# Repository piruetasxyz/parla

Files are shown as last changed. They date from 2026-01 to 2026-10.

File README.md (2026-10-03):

# parla

Un proyecto de piruetas, 2026.

## Módulos

Cada módulo tiene su propia carpeta con un proyecto de KiCad, organizado por versión y revisión (por ejemplo `parla-linea/parla-linea-v-0-rev-a/`).

| | parla-linea | parla-eurorack | parla-guitarra | parla-estereo |
| --- | --- | --- | --- | --- |
| formato | standalone | eurorack | standalone | standalone |
| entrada alimentación | batería 9V | por definir | batería 9V | por definir |
| chip | PAM8403 | por definir | LM386 | PAM8403 |
| interfaz | 1x pote | 2x potes | 1x pote | 2x potes |
| entrada señal | 1x línea TRS | 1x eurorack | 1x guitarra | 1x línea TRS |
| conector entrada | TRS 1/8" | TS 1/8" | TS 1/4" | TRS 1/8" |
| salidas | 1x parlante, 1x línea | 1x parlante, 1x eurorack | 1x parlante | 2x parlantes |
| conector salida | parlante: por definir, línea: TRS 1/8" | parlante: por definir, eurorack: TS 1/8" | parlante: por definir | parlantes: por definir |

### Extensores

| | parla-linea-extensor  | parla-eurorack-extensor |
| --- | --- | --- |
| formato | standalone | eurorack |
| alimentación | ninguna | por definir |
| chip | ninguno | por definir |
| interfaz | — | — |
| entradas | 1x línea | 1x eurorack |
| conector entrada | TRS 1/8" | TS 1/8" |
| salidas | 1x parlante | 1x parlante |
| conector salida  | parlante: por definir | parlante: por definir |

## Documentación

Esquemáticos, placas y bill of materials (BOM) de cada módulo, generados automáticamente: [docs](./docs/README.md).

### Agregar las bibliotecas de parla-linea a KiCad

Las bibliotecas generadas están en `parla-linea/parla-linea-v-0-rev-a/bibliotecas/`.
Para que KiCad las encuentre, abre primero el proyecto
`parla-linea/parla-linea-v-0-rev-a/parla-linea-v-0-rev-a.kicad_pro` y agrégalas
como bibliotecas específicas de ese proyecto:

1. En KiCad, abre **Preferencias → Administrar bibliotecas de símbolos…**.
2. En **Bibliotecas específicas del proyecto**, pulsa **Añadir biblioteca existente**
   y selecciona
   `parla-linea/parla-linea-v-0-rev-a/bibliotecas/parla-linea-v-0-rev-a.kicad_sym`.
3. Abre **Preferencias → Administrar bibliotecas de huellas…**.
4. En **Bibliotecas específicas del proyecto**, pulsa **Añadir biblioteca existente**
   y selecciona la carpeta
   `parla-linea/parla-linea-v-0-rev-a/bibliotecas/parla-linea-v-0-rev-a.pretty`
   (no un archivo dentro de ella).
5. Confirma los cambios. Las bibliotecas deberían aparecer en los selectores de
   símbolos y huellas del proyecto.

Agrégalas como bibliotecas **específicas del proyecto**, no globales, para que las
rutas queden asociadas a este proyecto. Los modelos 3D están en la carpeta hermana
`parla-linea/parla-linea-v-0-rev-a/bibliotecas/parla-linea-v-0-rev-a.3dshapes/`;
las huellas los referencian desde ahí, así que no hace falta registrarlos como
biblioteca aparte. Si el proyecto ya estaba abierto mientras agregabas las
bibliotecas, cierra y vuelve a abrir el proyecto.

### Enlaces por módulo

- parla-linea: [carpeta](https://github.com/piruetasxyz/parla/tree/main/parla-linea), [docs](./docs/parla-linea.md)
- parla-eurorack: [carpeta](https://github.com/piruetasxyz/parla/tree/main/parla-eurorack), [docs](./docs/parla-eurorack.md)
- parla-guitarra: [carpeta](https://github.com/piruetasxyz/parla/tree/main/parla-guitarra), [docs](./docs/parla-guitarra.md)
- parla-estereo: [carpeta](https://github.com/piruetasxyz/parla/tree/main/parla-estereo), [docs](./docs/parla-estereo.md)
- parla-linea-extensor: [carpeta](https://github.com/piruetasxyz/parla/tree/main/parla-linea-extensor), [docs](./docs/parla-linea-extensor.md)
- parla-eurorack-extensor: [carpeta](https://github.com/piruetasxyz/parla/tree/main/parla-eurorack-extensor), [docs](./docs/parla-eurorack-extensor.md)

## Versiones antiguas

Hicimos versiones preliminares que están en la carpeta [versiones-antiguas](https://github.com/piruetasxyz/parla/tree/main/versiones-antiguas):

- `parla-v0-borrador`: primeros experimentos de esquemáticos (enero-febrero 2026).
- `parla-v0-revA`: versión producida con SMD en JLCPCB.
- `parla-v0-revB`: revisión de la placa con algunos cambios (junio 2026), junto a sus gerbers y archivos de PCBA.
- `graficas`: logos y gráficas usadas en las placas.

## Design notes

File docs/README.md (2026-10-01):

# docs

Documentación por módulo: esquemático, placa y lista de materiales bill of materials (BOM) de la revisión activa de cada uno.

- [parla-linea](./parla-linea.md)
- [parla-linea-extensor](./parla-linea-extensor.md)
- [parla-eurorack](./parla-eurorack.md)
- [parla-eurorack-extensor](./parla-eurorack-extensor.md)
- [parla-guitarra](./parla-guitarra.md)
- [parla-estereo](./parla-estereo.md)

Las capturas SVG y las tablas BOM las genera [generar_docs.py](./generar_docs.py), que corre automáticamente en GitHub Actions (`.github/workflows/actualizar-capturas.yml`) en cada push a `main` que modifica un `.kicad_sch` o `.kicad_pcb`. La revisión activa de cada módulo es la carpeta `<modulo>-v-N-rev-X` más reciente dentro de `parla-*/`, así que al agregar una revisión o un módulo nuevo no hay que editar nada: el script lo detecta y, si el módulo es nuevo, crea su página acá (falta agregarla a mano a esta lista).

Para correrlo localmente (requiere `kicad-cli` de KiCad 10):

```sh
python3 docs/generar_docs.py
```

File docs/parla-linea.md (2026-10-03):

# parla-linea

[volver al índice](./README.md)

## Especificaciones

- formato: standalone
- interfaz: 2x potes
- entradas: 1x TRS 1/8"
- salidas: 1x parlante, 1x TRS 1/8"

## Revisión activa

`v-0-rev-a`

## Esquemático y placa

Generados automáticamente por GitHub Actions a partir de `parla-linea/parla-linea-v-0-rev-a/parla-linea-v-0-rev-a.kicad_sch` y `.kicad_pcb` en cada push que los modifica.

Esquemático de parla-linea v-0-rev-a

Placa de parla-linea v-0-rev-a

## Bill of materials

Generado a partir de `parla-linea/parla-linea-v-0-rev-a/parla-linea-v-0-rev-a.kicad_sch`.

<!-- BOM_TABLE_START -->
| Referencias | Cantidad | Valor | Huella | Descripción |
| --- | --- | --- | --- | --- |
| C1, C6 | 2 | 1u | parla-linea-v-0-rev-a:C0805 | Capacitor cerámico |
| C2, C7 | 2 | 100n | parla-linea-v-0-rev-a:C0805 | Capacitor cerámico |
| C3 | 1 | 100u | parla-linea-v-0-rev-a:CAP-SMD_BD6.3-L6.6-W6.6-LS7.6-FD | Capacitor electrolítico |
| C4 | 1 | 10u | parla-linea-v-0-rev-a:CAP-SMD_BD4.0-L4.3-W4.3-FD | Capacitor electrolítico |
| D1 | 1 | 1N4007 | parla-linea-v-0-rev-a:SOD-323_L1.8-W1.3-LS2.5-RD | Device:D |
| D2 | 1 | LED | Eurocad:LED3mm | Device:LED |
| J1, J2 | 2 | AudioJack2_SwitchT | Connector_Audio:Jack_3.5mm_QingPu_WQP-PJ398SM_Vertical_CircularHoles | Jack de audio mono |
| J3, J5 | 2 | Screw_Terminal_01x02 | TerminalBlock:TerminalBlock_MaiXu_MX126-5.0-02P_1x02_P5.00mm | Bornera de 2 pines |
| J4 | 1 | Conn_01x01 | Connector_Wire:SolderWire-0.25sqmm_1x01_D0.65mm_OD1.7mm | Connector_Generic:Conn_01x01 |
| J6 | 1 | AudioJack3_SwitchTR | Connector_Audio:Jack_3.5mm_CUI_SJ1-3525N_Horizontal | Connector_Audio:AudioJack3_SwitchTR |
| J7 | 1 | Conn_01x03_Pin | Connector_PinHeader_2.54mm:PinHeader_1x03_P2.54mm_Vertical | Connector:Conn_01x03_Pin |
| R1, R2 | 2 | 10k | parla-linea-v-0-rev-a:R0805 | Resistencia |
| R3 | 1 | 1k | parla-linea-v-0-rev-a:R0805 | Resistencia |
| RV1 | 1 | 100kB | Potentiometer_THT:Potentiometer_Alps_RK163_Dual_Horizontal | Device:R_Potentiometer_Dual_Separate |
| U1 | 1 | PAM8403D | parla-linea-v-0-rev-a:SOP-16_L10.0-W3.9-P1.27-LS6.0-BL | Amplificador de audio clase D |
| U2 | 1 | L7805 | parla-linea-v-0-rev-a:TO-252-2_L6.6-W6.1-P4.57-LS9.9-BR-CW | Regulador de voltaje lineal +5V |

21 componentes en total.
<!-- BOM_TABLE_END -->

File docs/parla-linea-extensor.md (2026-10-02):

# parla-linea-extensor

[volver al índice](./README.md)

## Especificaciones

- formato: standalone
- interfaz: —
- entradas: 1x TRS 1/8"
- salidas: 1x parlante

## Revisión activa

`v-0-rev-a`

## Esquemático y placa

Generados automáticamente por GitHub Actions a partir de `parla-linea-extensor/parla-linea-extensor-v-0-rev-a/parla-linea-extensor-v-0-rev-a.kicad_sch` y `.kicad_pcb` en cada push que los modifica.

Esquemático de parla-linea-extensor v-0-rev-a

Placa de parla-linea-extensor v-0-rev-a

## Bill of materials

Generado a partir de `parla-linea-extensor/parla-linea-extensor-v-0-rev-a/parla-linea-extensor-v-0-rev-a.kicad_sch`.

<!-- BOM_TABLE_START -->
| Referencias | Cantidad | Valor | Huella | Descripción |
| --- | --- | --- | --- | --- |
| J1 | 1 | AudioJack3_SwitchT | *(sin huella asignada)* | Jack de audio estéreo |
| LS1 | 1 | Speaker | TerminalBlock:TerminalBlock_MaiXu_MX126-5.0-02P_1x02_P5.00mm | Parlante |

2 componentes en total. Los ítems marcados *(sin huella asignada)* todavía no están completos en el esquemático — hay que completarlos antes de generar gerbers o comprar partes para esta revisión.
<!-- BOM_TABLE_END -->

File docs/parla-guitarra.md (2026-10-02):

# parla-guitarra

[volver al índice](./README.md)

## Especificaciones

- formato: standalone
- interfaz: 1x pote
- entradas: 1x TS 1/4"
- salidas: 1x parlante

## Revisión activa

`v-0-rev-a`

## Esquemático y placa

Generados automáticamente por GitHub Actions a partir de `parla-guitarra/parla-guitarra-v-0-rev-a/parla-guitarra-v-0-rev-a.kicad_sch` y `.kicad_pcb` en cada push que los modifica.

Esquemático de parla-guitarra v-0-rev-a

Placa de parla-guitarra v-0-rev-a

## Bill of materials

Generado a partir de `parla-guitarra/parla-guitarra-v-0-rev-a/parla-guitarra-v-0-rev-a.kicad_sch`.

<!-- BOM_TABLE_START -->
| Referencias | Cantidad | Valor | Huella | Descripción |
| --- | --- | --- | --- | --- |
| C3 | 1 | 220u | *(sin huella asignada)* | Capacitor electrolítico |
| C5 | 1 | 47u | *(sin huella asignada)* | Capacitor electrolítico |
| C6, C7, C9 | 3 | 100n | *(sin huella asignada)* | Capacitor cerámico |
| C8 | 1 | 47n | *(sin huella asignada)* | Capacitor cerámico |
| C10 | 1 | 100p | *(sin huella asignada)* | Capacitor cerámico |
| D1 | 1 | D | *(sin huella asignada)* | Device:D |
| D2, D3 | 2 | 1N4148 | Diode_THT:D_DO-35_SOD27_P7.62mm_Horizontal | Diode:1N4148 |
| J1 | 1 | entrada | *(sin huella asignada)* | Jack de audio mono |
| J2 | 1 | Screw_Terminal_01x02 | TerminalBlock:TerminalBlock_MaiXu_MX126-5.0-02P_1x02_P5.00mm | Bornera de 2 pines |
| LS1 | 1 | Speaker | TerminalBlock:TerminalBlock_MaiXu_MX126-5.0-02P_1x02_P5.00mm | Parlante |
| R1 | 1 | 10 | *(sin huella asignada)* | Resistencia |
| R2 | 1 | 1M | *(sin huella asignada)* | Resistencia |
| RV1 | 1 | 1k | *(sin huella asignada)* | Potenciómetro |
| U1 | 1 | LM386 | Package_DIP:DIP-8_W7.62mm_Socket_LongPads | Amplificador de audio LM386 |
| U2 | 1 | TL072 | *(sin huella asignada)* | Amplifier_Operational:TL072 |

18 componentes en total. Los ítems marcados *(sin huella asignada)* todavía no están completos en el esquemático — hay que completarlos antes de generar gerbers o comprar partes para esta revisión.
<!-- BOM_TABLE_END -->

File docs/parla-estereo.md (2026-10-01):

# parla-estereo

[volver al índice](./README.md)

## Especificaciones

- formato: standalone
- interfaz: 2x potes
- entradas: 1x TRS 1/8"
- salidas: 2x parlantes

## Revisión activa

`v-0-rev-a`

## Esquemático y placa

Generados automáticamente por GitHub Actions a partir de `parla-estereo/parla-estereo-v-0-rev-a/parla-estereo-v-0-rev-a.kicad_sch` y `.kicad_pcb` en cada push que los modifica.

Esquemático de parla-estereo v-0-rev-a

Placa de parla-estereo v-0-rev-a

## Bill of materials

Generado a partir de `parla-estereo/parla-estereo-v-0-rev-a/parla-estereo-v-0-rev-a.kicad_sch`.

<!-- BOM_TABLE_START -->
*(el esquemático todavía no tiene componentes)*
<!-- BOM_TABLE_END -->

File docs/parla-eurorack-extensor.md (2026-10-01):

# parla-eurorack-extensor

[volver al índice](./README.md)

## Especificaciones

- formato: eurorack
- interfaz: —
- entradas: 1x TS 1/8"
- salidas: 1x parlante

## Revisión activa

`v-0-rev-a`

## Esquemático y placa

Generados automáticamente por GitHub Actions a partir de `parla-eurorack-extensor/parla-eurorack-extensor-v-0-rev-a/parla-eurorack-extensor-v-0-rev-a.kicad_sch` y `.kicad_pcb` en cada push que los modifica.

Esquemático de parla-eurorack-extensor v-0-rev-a

Placa de parla-eurorack-extensor v-0-rev-a

## Bill of materials

Generado a partir de `parla-eurorack-extensor/parla-eurorack-extensor-v-0-rev-a/parla-eurorack-extensor-v-0-rev-a.kicad_sch`.

<!-- BOM_TABLE_START -->
*(el esquemático todavía no tiene componentes)*
<!-- BOM_TABLE_END -->

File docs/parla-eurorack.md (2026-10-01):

# parla-eurorack

[volver al índice](./README.md)

## Especificaciones

- formato: eurorack
- interfaz: 2x potes
- entradas: 1x TS 1/8"
- salidas: 1x parlante, 1x TS 1/8"

## Revisión activa

`v-0-rev-a`

## Esquemático y placa

Generados automáticamente por GitHub Actions a partir de `parla-eurorack/parla-eurorack-v-0-rev-a/parla-eurorack-v-0-rev-a.kicad_sch` y `.kicad_pcb` en cada push que los modifica.

Esquemático de parla-eurorack v-0-rev-a

Placa de parla-eurorack v-0-rev-a

## Bill of materials

Generado a partir de `parla-eurorack/parla-eurorack-v-0-rev-a/parla-eurorack-v-0-rev-a.kicad_sch`.

<!-- BOM_TABLE_START -->
*(el esquemático todavía no tiene componentes)*
<!-- BOM_TABLE_END -->

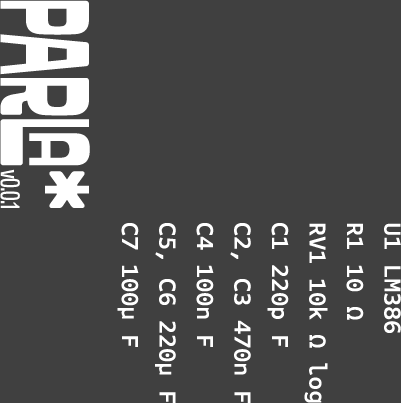
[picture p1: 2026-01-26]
versiones-antiguas/graficas/parla_info_square@300x.png

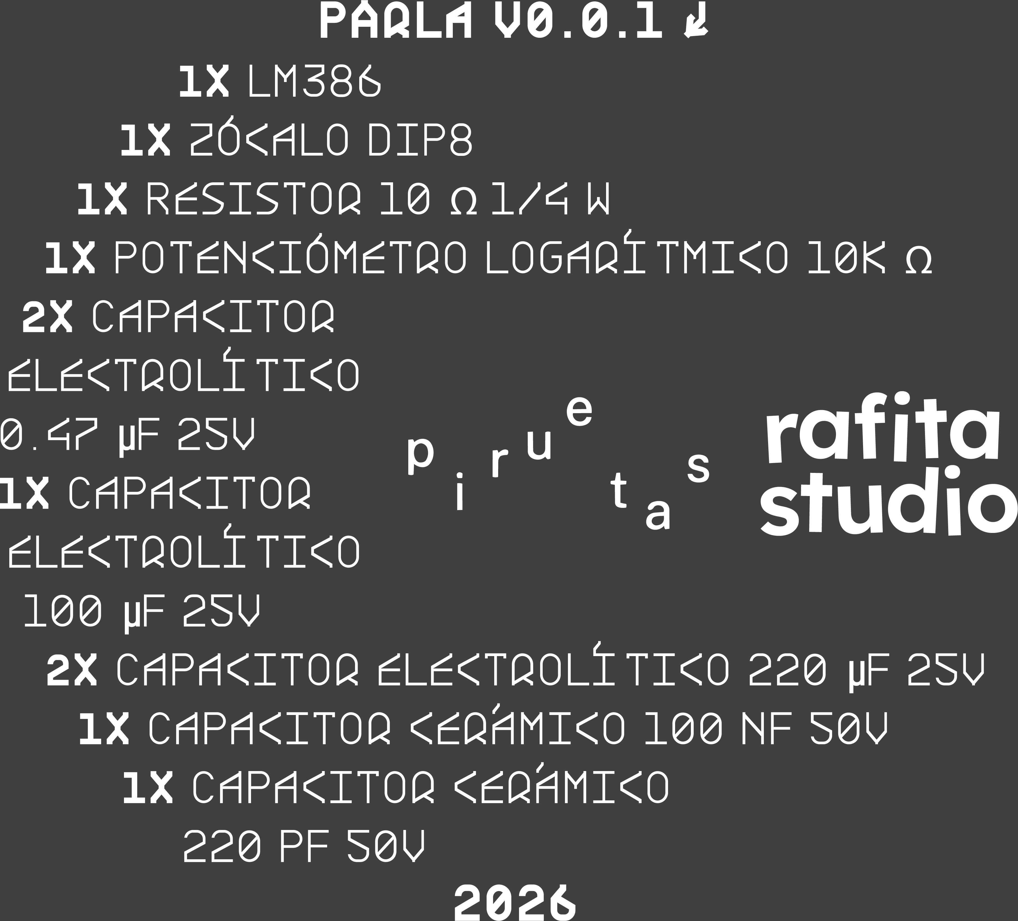
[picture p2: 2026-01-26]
versiones-antiguas/graficas/parla_info@300x.png

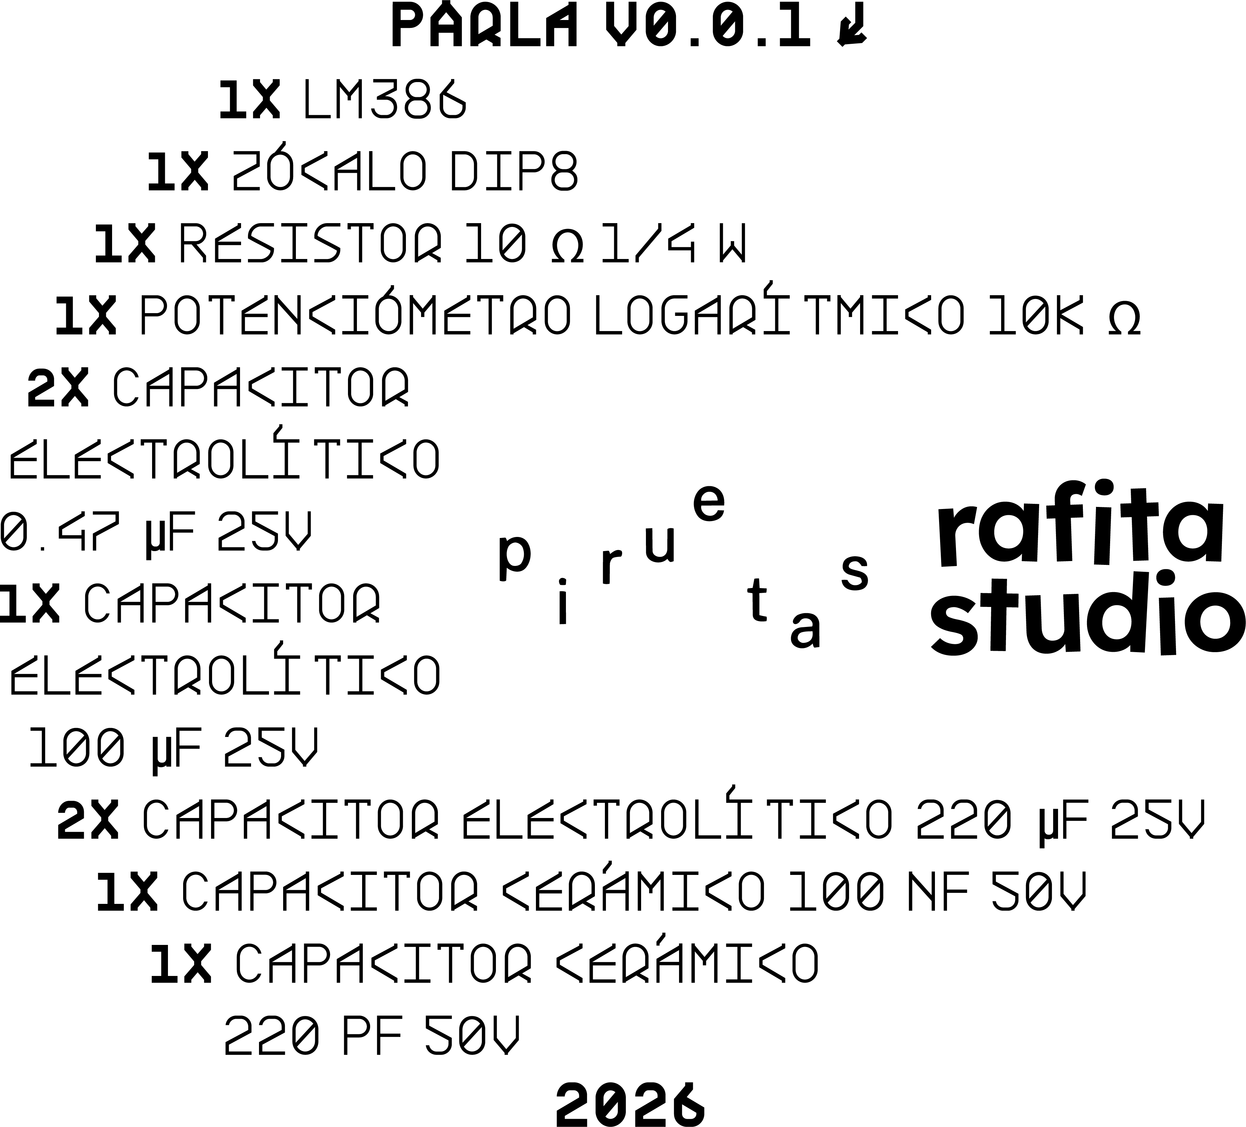
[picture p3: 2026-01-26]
versiones-antiguas/graficas/parla_infoBlack@300x.png

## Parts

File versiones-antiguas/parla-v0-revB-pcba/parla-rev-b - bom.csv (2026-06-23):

Comment | Designator | Footprint | LCSC Part Number
470n | C1,C2 | Capacitor_SMD:C_Elec_4x5.4 | C2895732
100n | C3,C10 | Capacitor_SMD:C_0805_2012Metric_Pad1.18x1.45mm_HandSolder | C49678
1u | C4,C5,C6 | Capacitor_SMD:C_0805_2012Metric_Pad1.18x1.45mm_HandSolder | C77083
100u | C7 | Capacitor_SMD:CP_Elec_6.3x7.7 | C3347
220u | C8 | Capacitor_SMD:CP_Elec_6.3x5.4 | C3342
10u | C9 | Capacitor_SMD:CP_Elec_4x5.4 | C3357
1N4007 | D1 | Diode_SMD:D_SOD-323_HandSoldering | C193404
10k | R3,R4 | Resistor_SMD:R_0805_2012Metric_Pad1.20x1.40mm_HandSolder | C17414
1k | R5 | Resistor_SMD:R_0805_2012Metric_Pad1.20x1.40mm_HandSolder | C2907232
PAM8403D | U1 | Package_SO:SOP-16_4.4x10.4mm_P1.27mm | C5122557
L7805 | U2 | Package_TO_SOT_SMD:TO-252-2 | C19626525

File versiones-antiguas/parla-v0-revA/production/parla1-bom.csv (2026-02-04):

Comment | Designator | Footprint | LCSC Part Number
220p | C1 | C_0805_2012Metric | C107145
470n | C2,C3 | CP_Elec_4x5.4 | C22387960
100n | C4 | C_0805_2012Metric | C49678
220u | C5,C6 | CP_Elec_6.3x5.4 | C3345
100u | C7 | CP_Elec_5x5.4 | C72473
1n4007 | D1 | D_SOD-323 | C193404
10R | R1 | R_0805_2012Metric | C2907296

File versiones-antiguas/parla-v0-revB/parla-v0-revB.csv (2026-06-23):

Reference | Value | Footprint | LCSC
C1,C2 | 470n | Capacitor_SMD:C_Elec_4x5.4 | C2895732
C3,C10 | 100n | Capacitor_SMD:C_0805_2012Metric_Pad1.18x1.45mm_HandSolder | C49678
C4,C5,C6 | 1u | Capacitor_SMD:C_0805_2012Metric_Pad1.18x1.45mm_HandSolder | C77083
C7 | 100u | Capacitor_SMD:CP_Elec_5x5.4 | C3347
C8 | 220u | Capacitor_SMD:CP_Elec_6.3x7.7 | C3342
C9 | 10u | Capacitor_SMD:CP_Elec_4x5.4 | C3357
D1 | 1N4007 | Diode_SMD:D_SOD-323_HandSoldering | C193404
D8 | LED | LED_THT:LED_D5.0mm
J1,J2,J3,J4 | AudioJack2_SwitchT | dis8644:PJ301M-12-T_TN_S
J5 | Barrel_Jack_Switch | Connector_BarrelJack:BarrelJack_Horizontal
R3,R4 | 10k | Resistor_SMD:R_0805_2012Metric_Pad1.20x1.40mm_HandSolder | C17414
R5 | 1k | Resistor_SMD:R_0805_2012Metric_Pad1.20x1.40mm_HandSolder | C2907232
RV1,RV2 | 50k | Potentiometer_THT:Potentiometer_Bourns_PTV09A-1_Single_Vertical
SW3 | SW_SPDT | dis8644:spdt_ssd12d00g3
U1 | PAM8403D | Package_SO:SOP-16_4.4x10.4mm_P1.27mm | C5122557
U2 | L7805 | Package_TO_SOT_SMD:TO-252-2 | C19626525

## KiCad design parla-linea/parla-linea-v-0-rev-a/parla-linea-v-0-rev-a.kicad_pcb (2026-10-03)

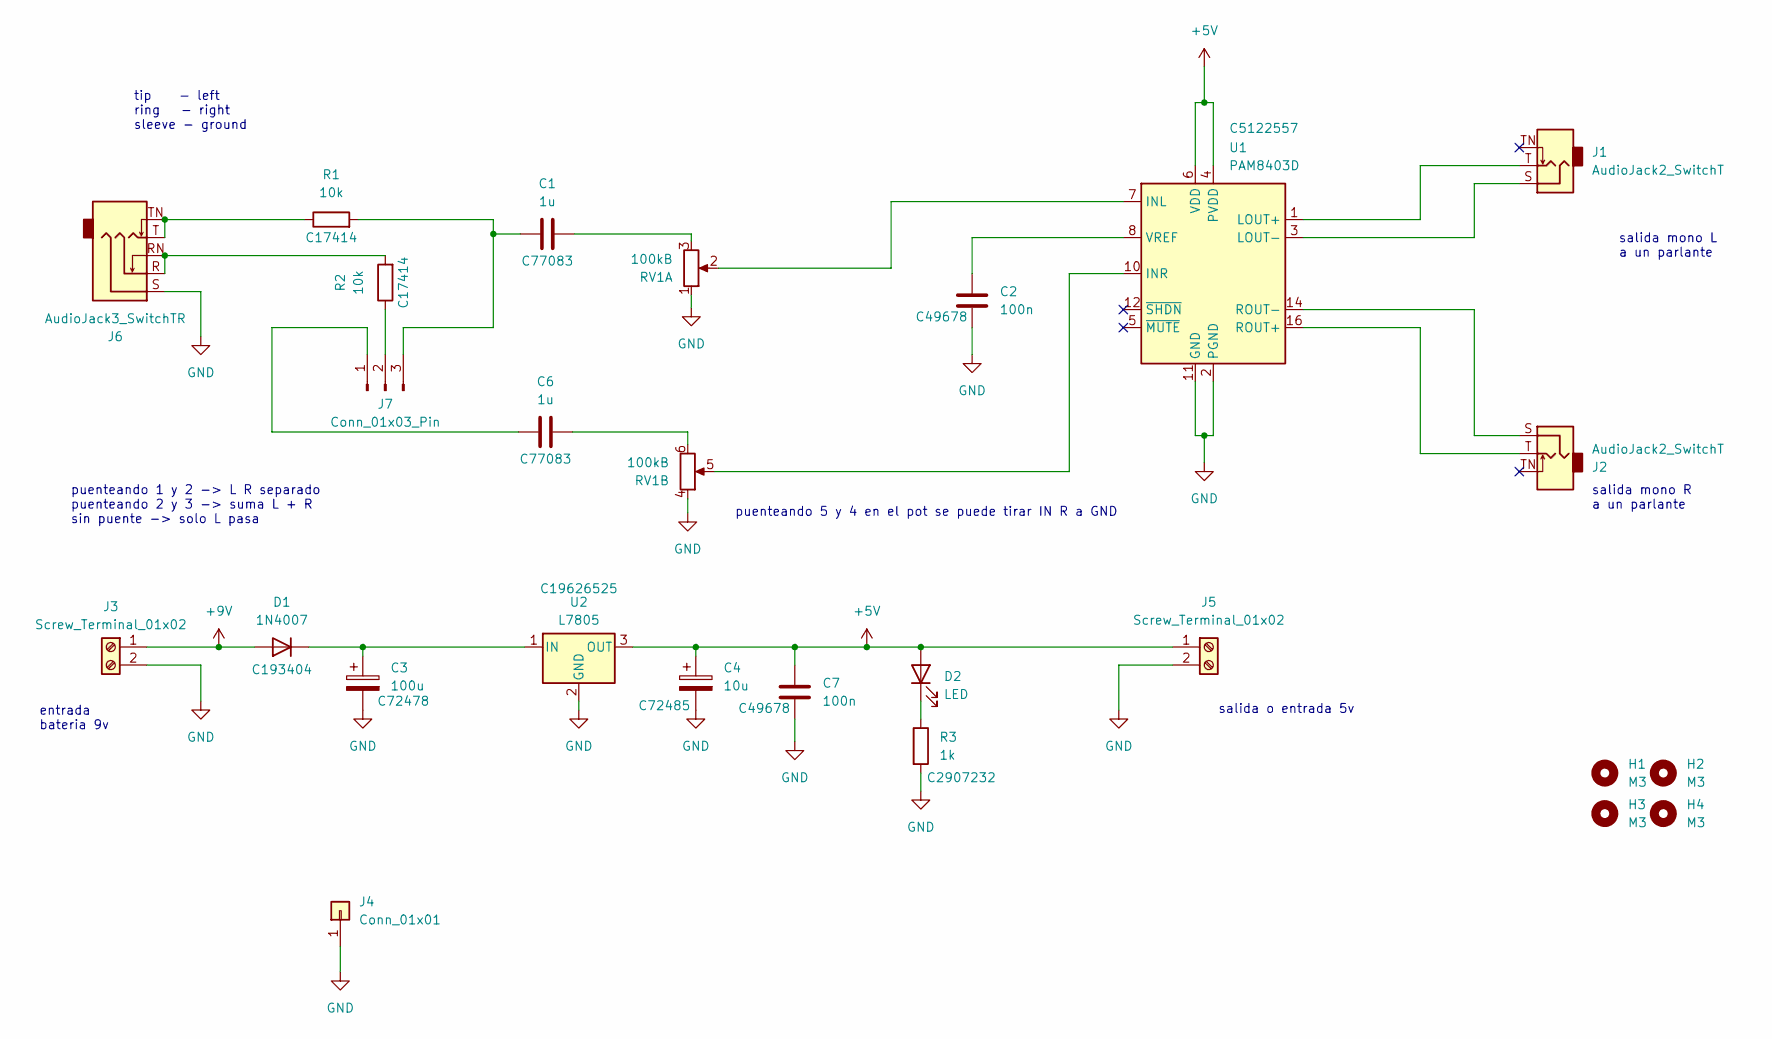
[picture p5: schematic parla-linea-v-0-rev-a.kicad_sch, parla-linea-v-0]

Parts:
C1, C6: 1u; C0805; LCSC C77083
C2, C7: 100n; C0805; LCSC C49678
C3: 100u; CAP-SMD_BD6.3-L6.6-W6.6-LS7.6-FD; LCSC C72478
C4: 10u; CAP-SMD_BD4.0-L4.3-W4.3-FD; LCSC C72485
D1: 1N4007; SOD-323_L1.8-W1.3-LS2.5-RD; LCSC C193404
D2: LED; LED3mm
H1, H2, H3, H4: M3; MountingHole_3.2mm_M3
J1, J2: AudioJack2_SwitchT; Jack_3.5mm_QingPu_WQP-PJ398SM_Vertical_CircularHoles
J3, J5: Screw_Terminal_01x02; TerminalBlock_MaiXu_MX126-5.0-02P_1x02_P5.00mm
J4: Conn_01x01; SolderWire-0.25sqmm_1x01_D0.65mm_OD1.7mm
J6: AudioJack3_SwitchTR; Jack_3.5mm_CUI_SJ1-3525N_Horizontal
J7: Conn_01x03_Pin; PinHeader_1x03_P2.54mm_Vertical
R1, R2: 10k; R0805; LCSC C17414
R3: 1k; R0805; LCSC C2907232
RV1: 100kB; Potentiometer_Alps_RK163_Dual_Horizontal
U1: PAM8403D; SOP-16_L10.0-W3.9-P1.27-LS6.0-BL; LCSC C5122557
U2: L7805; TO-252-2_L6.6-W6.1-P4.57-LS9.9-BR-CW; LCSC C19626525

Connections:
+5V: C4.1, C7.1, D2.2 (A), J5.1, U1.4 (PVDD), U1.6 (VDD), U1.13 (PVDD), U2.3 (OUT)
+9V: D1.2 (A), J3.1
GND: C2.2, C3.2, C4.2, C7.2, J3.2, J4.1 (Pin_1_1), J5.2, J6.S, R3.2, RV1.1, RV1.4, U1.2 (PGND), U1.11 (GND), U1.15 (PGND), U2.2 (GND)
unnamed: C1.2, RV1.3
unnamed: C6.2, RV1.6
unnamed: C3.1, D1.1 (K), U2.1 (IN)
unnamed: D2.1 (K), R3.1
unnamed: J6.R, J6.RN, R2.2
unnamed: J6.T, J6.TN, R1.1
unnamed: C6.1, J7.1
unnamed: J7.2, R2.1
unnamed: C1.1, J7.3, R1.2
unnamed: RV1.2, U1.7 (INL)
unnamed: RV1.5, U1.10 (INR)
unnamed: J1.T, U1.1 (LOUT+)
unnamed: J1.S, U1.3 (LOUT-)
unnamed: J2.T, U1.16 (ROUT+)
unnamed: J2.S, U1.14 (ROUT-)
unnamed: C2.1, U1.8 (VREF)

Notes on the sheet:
salida mono L a un parlante
tip - left ring - right sleeve - ground
salida mono R a un parlante
puenteando 1 y 2 -> L R separado puenteando 2 y 3 -> suma L + R sin puente -> solo L pasa
entrada bateria 9v
puenteando 5 y 4 en el pot se puede tirar IN R a GND
salida o entrada 5v

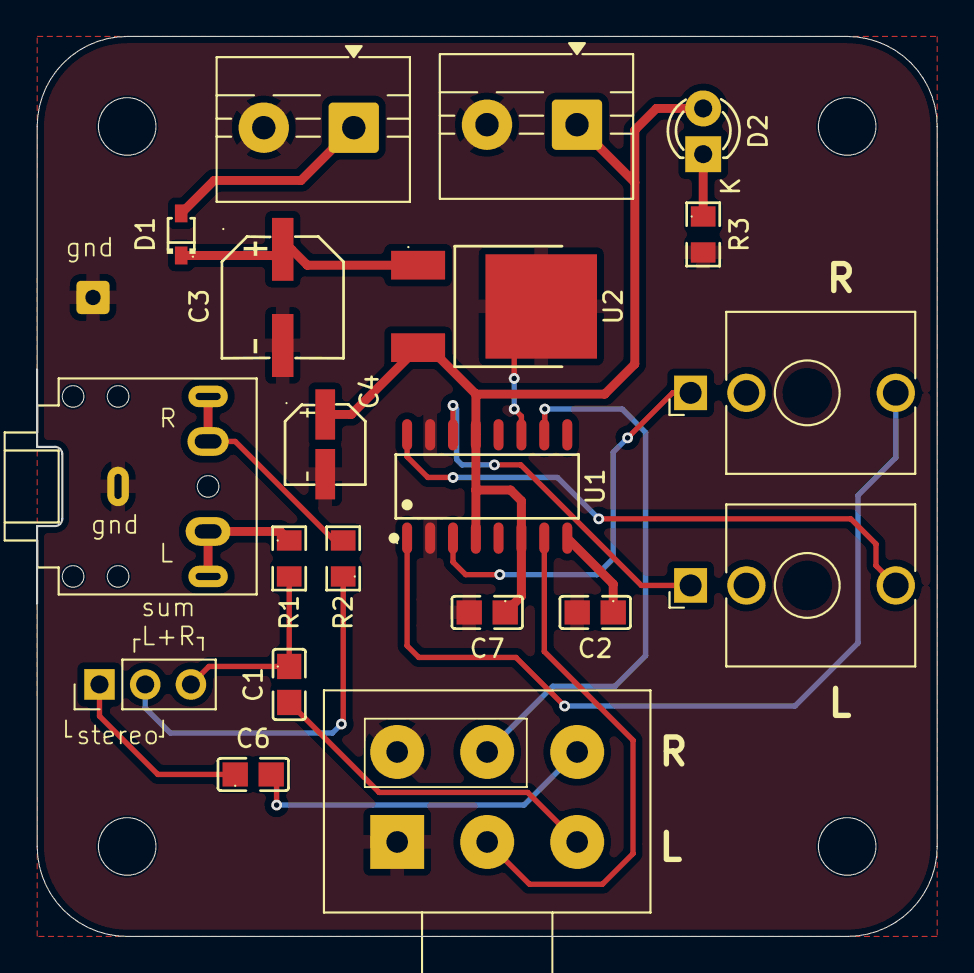
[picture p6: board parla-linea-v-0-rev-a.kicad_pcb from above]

Board: 2 copper layers, 50.0 x 50.0 mm, 25 parts (0 on the bottom side), 19 nets.

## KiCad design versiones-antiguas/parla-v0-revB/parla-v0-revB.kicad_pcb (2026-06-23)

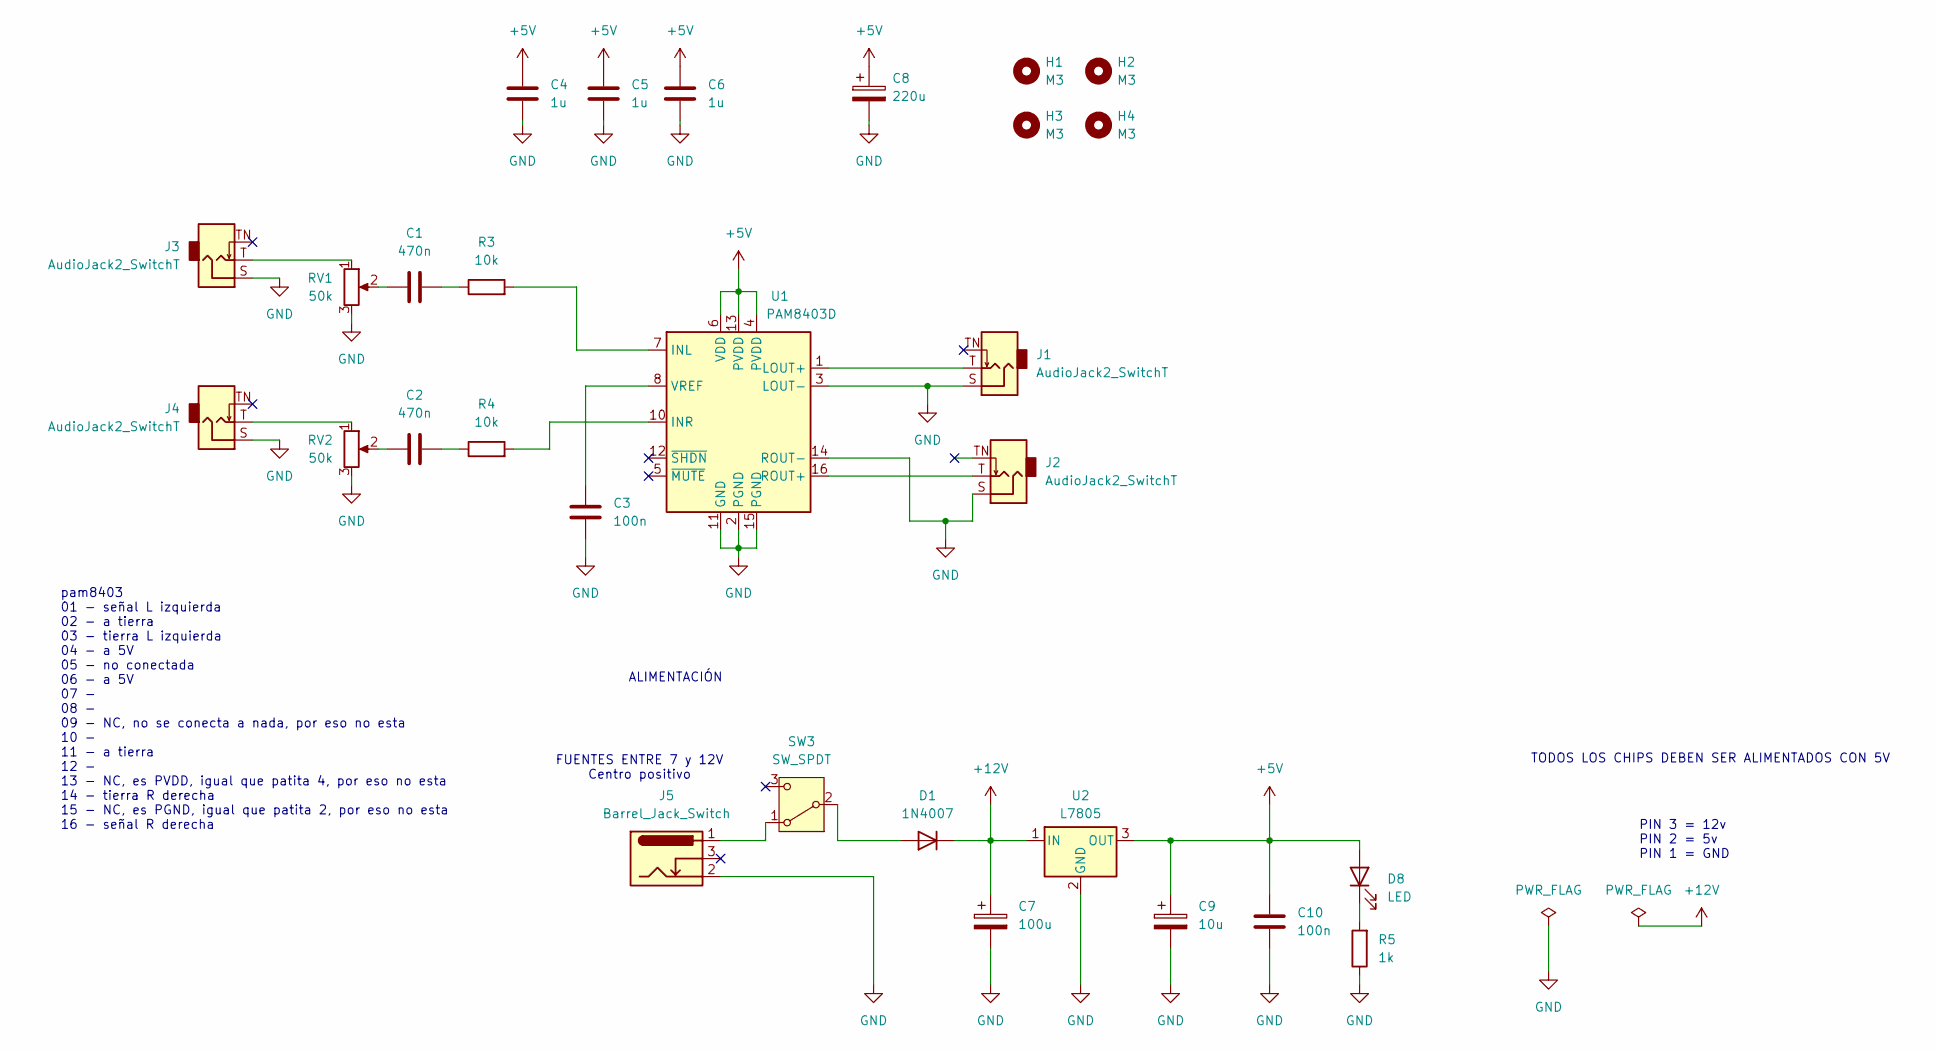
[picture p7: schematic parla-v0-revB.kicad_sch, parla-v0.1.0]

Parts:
C1, C2: 470n; C_Elec_4x5.4; LCSC C2895732
C3, C10: 100n; C_0805_2012Metric_Pad1.18x1.45mm_HandSolder; LCSC C49678
C4, C5, C6: 1u; C_0805_2012Metric_Pad1.18x1.45mm_HandSolder; LCSC C77083
C7: 100u; CP_Elec_5x5.4; LCSC C3347
C8: 220u; CP_Elec_6.3x7.7; LCSC C3342
C9: 10u; CP_Elec_4x5.4; LCSC C3357
D1: 1N4007; D_SOD-323_HandSoldering; LCSC C193404
D8: LED; LED_D5.0mm
H1, H2, H3, H4: M3; MountingHole_3.2mm_M3
J1, J2, J3, J4: AudioJack2_SwitchT; PJ301M-12-T_TN_S
J5: Barrel_Jack_Switch; BarrelJack_Horizontal
R3, R4: 10k; R_0805_2012Metric_Pad1.20x1.40mm_HandSolder; LCSC C17414
R5: 1k; R_0805_2012Metric_Pad1.20x1.40mm_HandSolder; LCSC C2907232
RV1, RV2: 50k; Potentiometer_Bourns_PTV09A-1_Single_Vertical
SW3: SW_SPDT; spdt_ssd12d00g3
U1: PAM8403D; SOP-16_4.4x10.4mm_P1.27mm; LCSC C5122557
U2: L7805; TO-252-2; LCSC C19626525

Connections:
+5V: C4.2, C5.2, C6.2, C8.1, C9.1, C10.1, D8.2 (A), U1.4 (PVDD), U1.6 (VDD), U1.13 (PVDD), U2.3 (OUT)
+12V: C7.1, D1.1 (K), U2.1 (IN)
GND: C3.2, C4.1, C5.1, C6.1, C7.2, C8.2, C9.2, C10.2, J1.S, J2.S, J3.S, J4.S, J5.2, R5.1, RV1.3, RV2.3, U1.2 (PGND), U1.3 (LOUT-), U1.11 (GND), U1.14 (ROUT-), U1.15 (PGND), U2.2 (GND)
unnamed: C1.1, RV1.2
unnamed: C1.2, R3.1
unnamed: C2.1, RV2.2
unnamed: C2.2, R4.1
unnamed: D1.2 (A), SW3.2 (B)
unnamed: D8.1 (K), R5.2
unnamed: J3.T, RV1.1
unnamed: J4.T, RV2.1
unnamed: J5.1, SW3.1 (A)
unnamed: R3.2, U1.7 (INL)
unnamed: R4.2, U1.10 (INR)
unnamed: J1.T, U1.1 (LOUT+)
unnamed: J2.T, U1.16 (ROUT+)
unnamed: C3.1, U1.8 (VREF)

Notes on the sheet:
FUENTES ENTRE 7 y 12V Centro positivo
PIN 3 = 12v PIN 2 = 5v PIN 1 = GND
TODOS LOS CHIPS DEBEN SER ALIMENTADOS CON 5V
ALIMENTACIÓN
pam8403 01 - señal L izquierda 02 - a tierra 03 - tierra L izquierda 04 - a 5V 05 - no conectada 06 - a 5V 07 - 08 - 09 - NC, no se conecta a nada, por eso no esta 10 - 11 - a tierra 12 - 13 - NC, es PVDD, igual que patita 4, por eso no esta 14 - tierra R derecha 15 - NC, es PGND, igual que patita 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

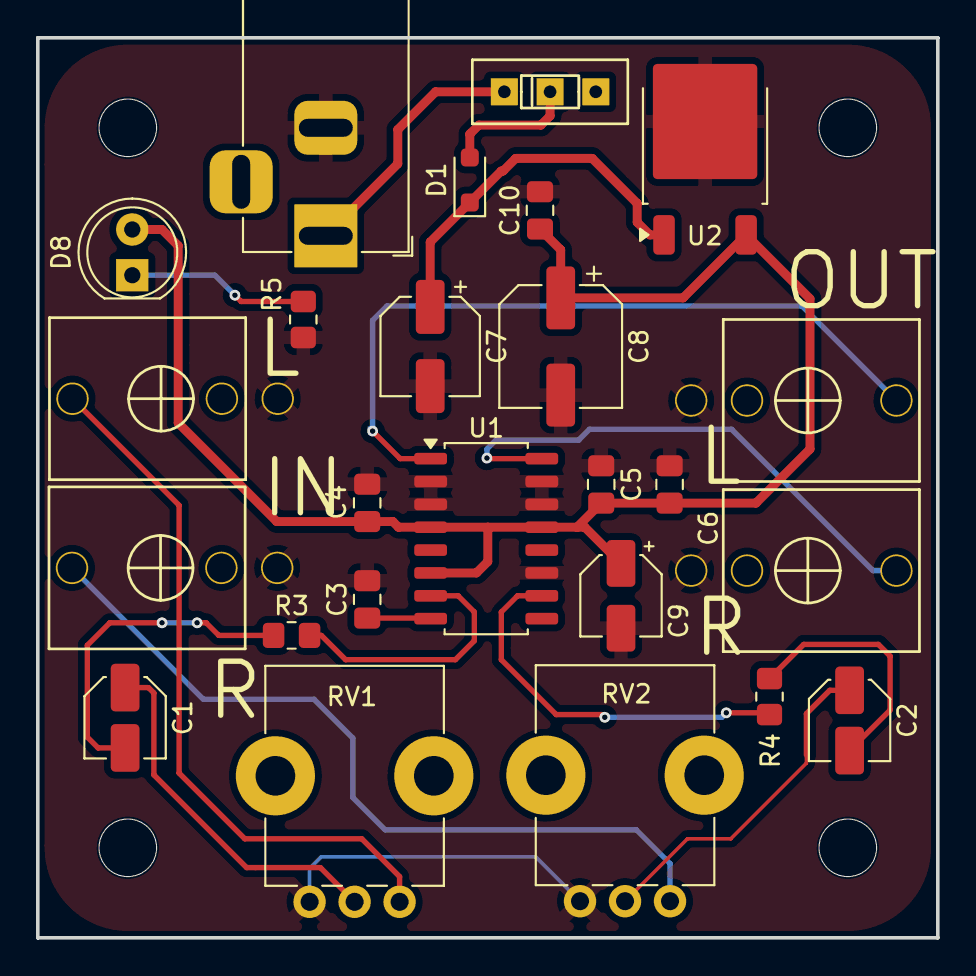
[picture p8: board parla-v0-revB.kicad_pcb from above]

Board: 2 copper layers, 50.0 x 50.0 mm, 29 parts (0 on the bottom side), 17 nets.

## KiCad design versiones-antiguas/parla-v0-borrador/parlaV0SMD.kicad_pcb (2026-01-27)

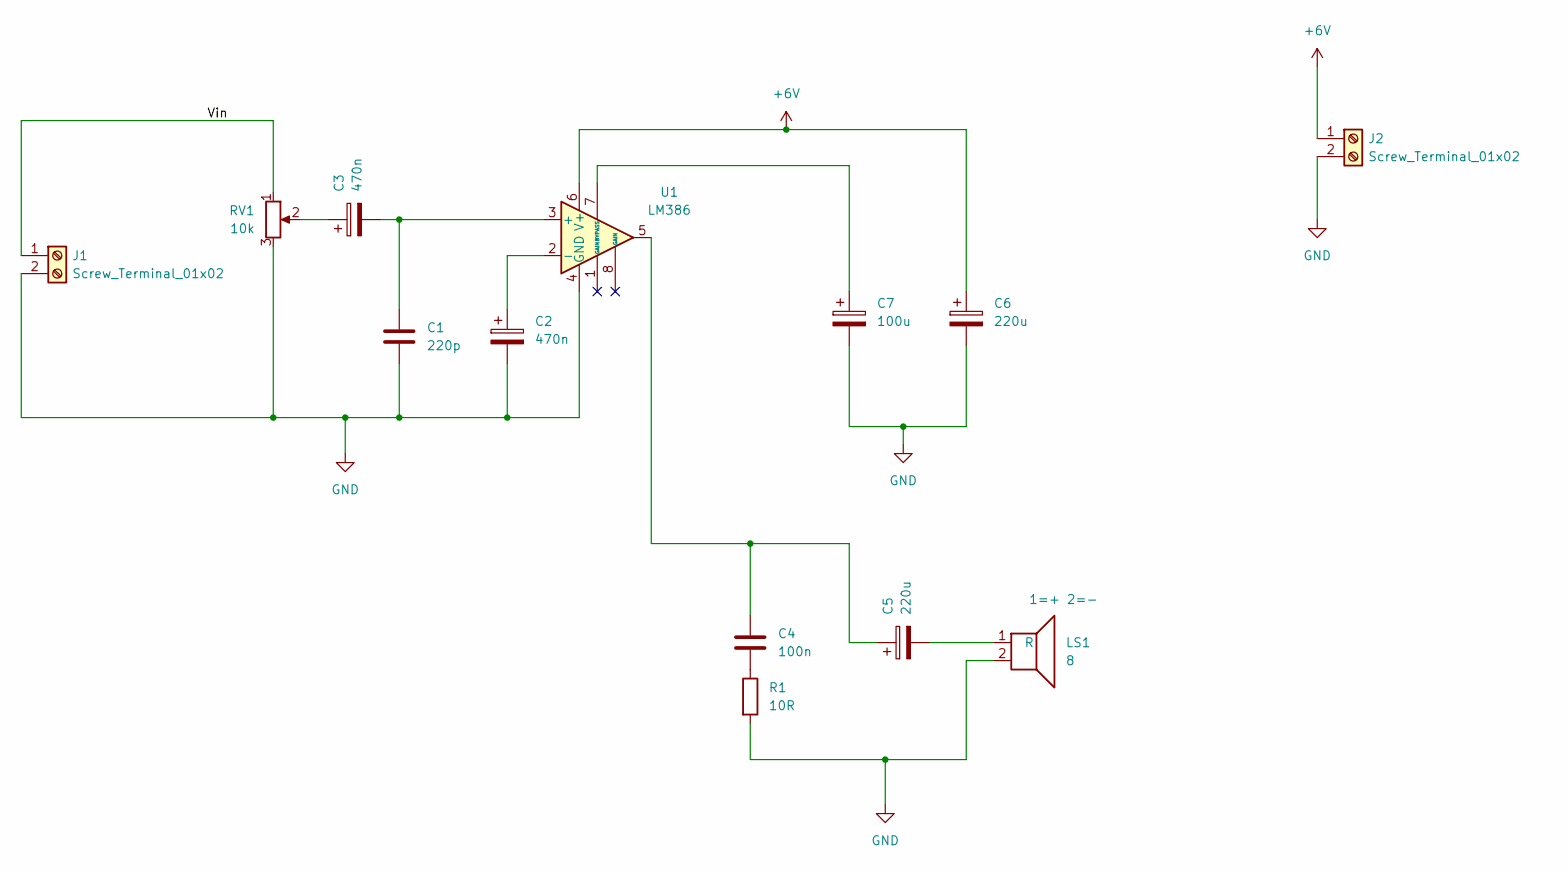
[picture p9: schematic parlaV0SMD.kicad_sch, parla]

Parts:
C1: 220p; C_0805_2012Metric
C2, C3: 470n; CP_Elec_6.3x7.7
C4: 100n; C_0805_2012Metric
C5, C6: 220u; CP_Elec_6.3x7.7
C7: 100u; CP_Elec_6.3x7.7
J1, J2: Screw_Terminal_01x02; TerminalBlock_Phoenix_PT-1,5-2-3.5-H_1x02_P3.50mm_Horizontal
LS1: 8; TerminalBlock_Phoenix_MPT-0,5-2-2.54_1x02_P2.54mm_Horizontal
R1: 10R; R_1206_3216Metric
RV1: 10k; TerminalBlock_Phoenix_PT-1,5-3-3.5-H_1x03_P3.50mm_Horizontal
U1: LM386; DIP-8_W7.62mm

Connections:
+6V: C6.1, J2.1, U1.6 (V+)
/Vin: J1.1, RV1.1
GND: C1.2, C2.2, C6.2, C7.2, J1.2, J2.2, LS1.2, R1.2, RV1.3, U1.4 (GND)
unnamed: C3.1, RV1.2
unnamed: C4.1, C5.1, U1.5
unnamed: C4.2, R1.1
unnamed: C5.2, LS1.1
unnamed: C1.1, C3.2, U1.3 (+)
unnamed: C2.1, U1.2 (-)
unnamed: C7.1, U1.7 (BYPASS)

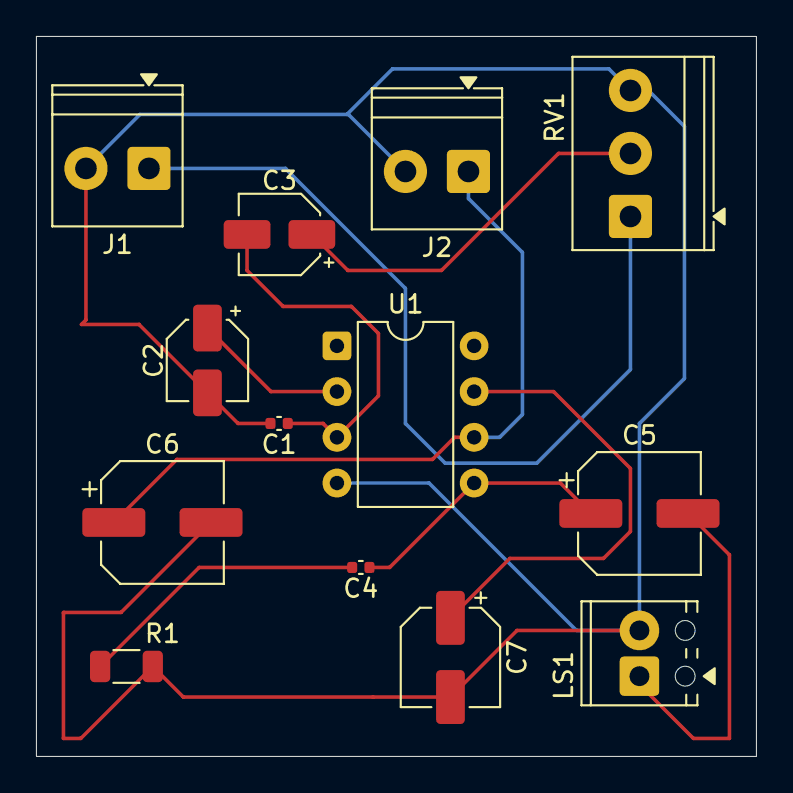
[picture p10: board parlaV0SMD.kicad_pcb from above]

Board: 2 copper layers, 40.0 x 40.0 mm, 13 parts (0 on the bottom side), 10 nets.

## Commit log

2026-01-15 agregar kicad a gitignore
2026-01-15 agregar carpeta de kicad v0
    [parlaV0.kicad_pcb, parlaV0.kicad_sch]
2026-01-16 agregar borrador circuito
    [parlaV0.kicad_sch]
2026-01-16 agregar footprints
    [parlaV0.kicad_pcb, parlaV0.kicad_sch]
2026-01-16 agregar edgecuts
    [parlaV0.kicad_pcb]
2026-01-16 agregar logo
    [parlaV0.kicad_pcb, parlaV0.kicad_sch]
2026-01-26 resetear pcb, agregar stereo
    [parlaStereo.kicad_pcb, parlaStereo.kicad_sch, parlaV0.kicad_pcb]
2026-01-26 agregar componentes ahora en SMD
    [parlaV0SMD.kicad_sch]
2026-01-26 agregar nuevas graficas, falta wiring
    [parlaV0SMD.kicad_pcb]
2026-01-26 añadidos comentarios sch
    [parlaV0SMD.kicad_sch]
2026-01-26 resueltos comentarios mati
    [parlaV0SMD.kicad_sch]
2026-01-26 agregar nuevo ruteo
    [parlaV0SMD.kicad_pcb, parlaV0SMD.kicad_sch]
2026-01-27 agregar csv
    [parlaV0SMD-B_Cu.gbr, parlaV0SMD-B_Mask.gbr, parlaV0SMD-B_Paste.gbr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]
2026-02-04 añadida parlaV1 by misaa
    [parla1-bom.csv, parlaV0.kicad_sch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]
2026-06-02 borrar parla-stereo
    [parlaStereo.kicad_pcb, parlaStereo.kicad_sch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]
2026-06-02 mover una carpeta arriba
    [parla1-bom.csv, parlaV0.kicad_sch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]
2026-06-02 mover a revA
    [parla1-bom.csv, parlaV0.kicad_sch, parlaV0SMD.kicad_pcb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]
2026-06-06 subir reorden
    [parla-v0-revB.kicad_pcb, parla-v0-revB.kicad_sch, parla1-bom.csv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]
2026-06-07 agregar vias
    [parla-v0-revB.kicad_pcb, parla-v0-revB.kicad_sch]
2026-06-23 nueva version matias
    [parla-v0-revB.kicad_pcb, parla-v0-revB.kicad_sch]
2026-06-23 agregar mis cambios
    [parla-v0-revB-B_Cu.gbr, parla-v0-revB-B_Mask.gbr, parla-v0-revB-B_Silkscreen.gbr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]
2026-06-23 editadas huellas standard
    [parla-v0-revB.kicad_pcb, parla-v0-revB.kicad_sch]
2026-06-23 borrar gerbers antiguos
    [parla-v0-revB-B_Cu.gbr, parla-v0-revB-B_Mask.gbr, parla-v0-revB-B_Silkscreen.gbr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]
2026-06-23 borrar csvs antiguos
    [parla-v0-revB.csv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]
2026-06-23 agregar archivos de produccion
    [parla-rev-b - bom.csv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]
2026-09-20 agregar borrador parla-guitarra-v-0
    [parla-guitarra-v-0.kicad_pcb, parla-guitarra-v-0.kicad_sch]
2026-09-30 agregar borrador
    [parla-guitarra-v-0.kicad_sch]
2026-09-30 movi todas las hechas hasta ahora a primeras versiones
    [parla-rev-b - bom.csv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]
2026-09-30 mover a versiones antiguas
    [parla-guitarra-v-0-rev-a.kicad_pcb, parla-guitarra-v-0-rev-a.kicad_sch, parla-guitarra-v-0.kicad_pcb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]
2026-10-01 agregar archivos en blanco
    [parla-estereo-v-0-rev-a.kicad_pcb, parla-estereo-v-0-rev-a.kicad_sch, parla-eurorack-extensor-v-0-rev-a.kicad_pcb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]
2026-10-01 Actualizar capturas y BOM de esquemáticos y placas [skip ci]
2026-10-01 nueva docs
    [parla-guitarra-v-0-rev-a.kicad_sch]
2026-10-01 agregar nueva forma de la tabla
2026-10-01 agregar borde pcb
    [parla-guitarra-v-0-rev-a.kicad_pcb, parla-guitarra-v-0-rev-a.kicad_sch]
2026-10-01 agregar terminal block
    [parla-guitarra-v-0-rev-a.kicad_sch]
2026-10-02 agregar mas apuntes
    [parla-guitarra-v-0-rev-a.kicad_sch, parla-linea-v-0-rev-a.kicad_sch]
2026-10-02 agregar parla-guitarra borrador
    [parla-guitarra-v-0-rev-a.kicad_sch]
2026-10-02 nueva version de parla linea
    [parla-linea-v-0-rev-a.kicad_sch]
2026-10-02 agregar mas sobre parla linea extensor
    [parla-linea-extensor-v-0-rev-a.kicad_sch, parla-linea-v-0-rev-a.kicad_sch]
2026-10-03 añadidos componentes lcsc
    [parla-linea-v-0-rev-a.kicad_sch]
2026-10-03 agregar pcba
    [parla-linea-v-0-rev-a-B_Cu.gbr, parla-linea-v-0-rev-a-B_Mask.gbr, parla-linea-v-0-rev-a-B_Silkscreen.gbr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]
